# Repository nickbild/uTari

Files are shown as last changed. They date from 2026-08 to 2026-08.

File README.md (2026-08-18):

# µTari

µTari (pronounced micro-Tari) is an Atari 2600, only smaller. 

An original 2600 PCB measures about 9.75 x 5.25 inches. The µTari PCB is 4.7 x 3.5 inches, making it roughly one-third the size of the original. All of the original chips (6507 CPU, TIA, RIOT) were used in making the µTari — it's the real deal, not an emulator or FPGA.

<table>
  <tr>
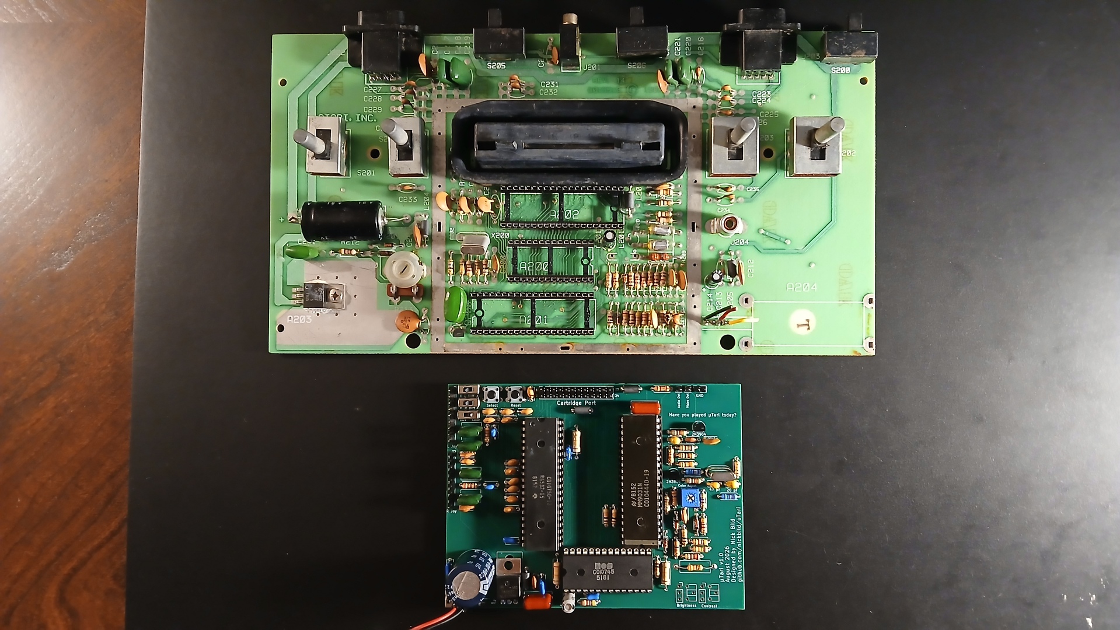
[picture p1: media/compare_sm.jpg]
Original Atari 2600 PCB compared with the smaller µTari PCB
    <td></td>
  </tr>
  <tr>
    <td align="center"><em>Original Atari 2600 PCB (top) compared with the µTari PCB (bottom).</em></td>
  </tr>
</table>

**Check out the video on YouTube:**
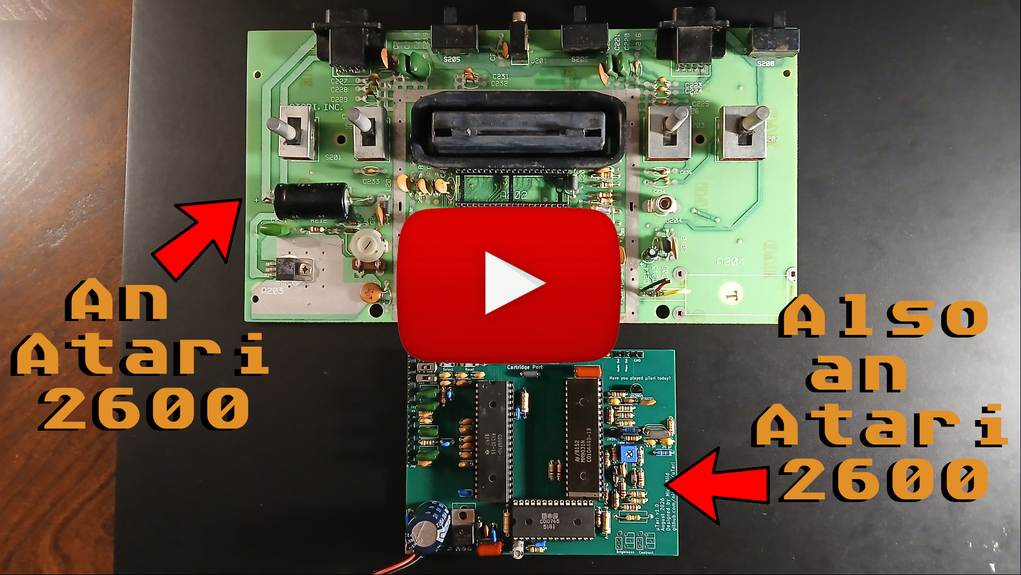
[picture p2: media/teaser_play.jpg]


## How

The Atari 2600 has large switches, as well as controller and cartridge ports, that are quite nice to have for a home console. I have replaced the large switches with tiny switches and buttons. The ports have been replaced with pin headers because my eventual plan is to turn this into a handheld, so I don't want ports on the main board.

Aside from that, I removed the RF modulator (which is normally at the bottom right of the 2600 PCB) and did a composite mod that replaces it with a single transistor and two resistors. That saves a fair amount of space and produces a cleaner signal that is compatible with more modern TVs. Empty spaces on the original PCB were also cut out. 

The remainder of the circuit is copied from the original Atari PCB. The 6507, TIA, and RIOT were transplanted to the new board. Since the rest of the components (mostly resistors, capacitors, transistors, and such) can still be purchased new, I used brand-new parts to leave the original board as intact as possible. All I would need to do is pop the chips back in the IC sockets for the 2600 to work again — no Ataris were harmed in the making of the µTari.

I started by breadboarding the circuit:

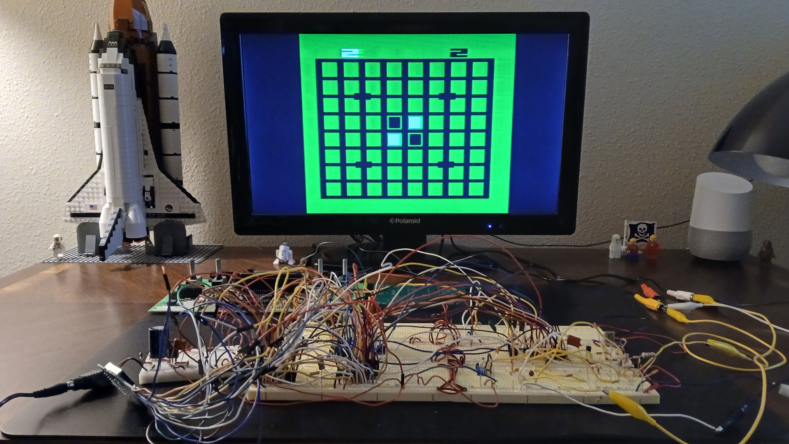
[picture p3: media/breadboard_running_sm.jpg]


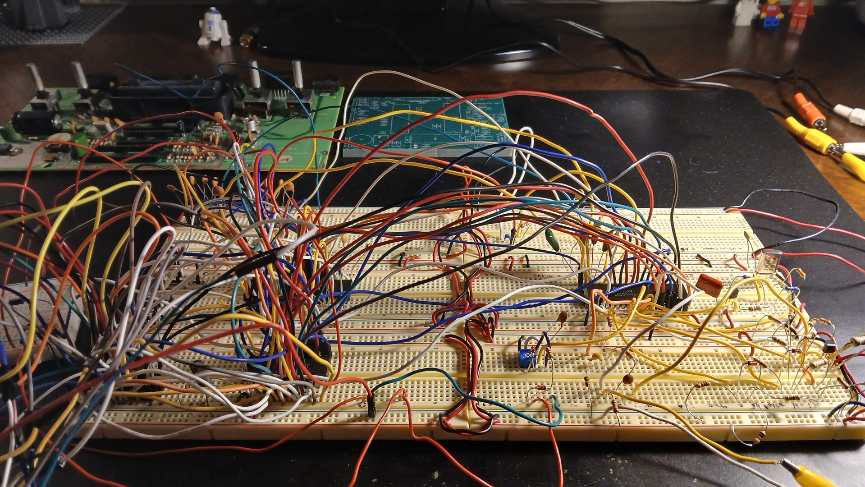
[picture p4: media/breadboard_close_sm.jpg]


Once I was convinced it was working properly, I drew the circuit diagram in KiCad before laying out a PCB and having it manufactured:

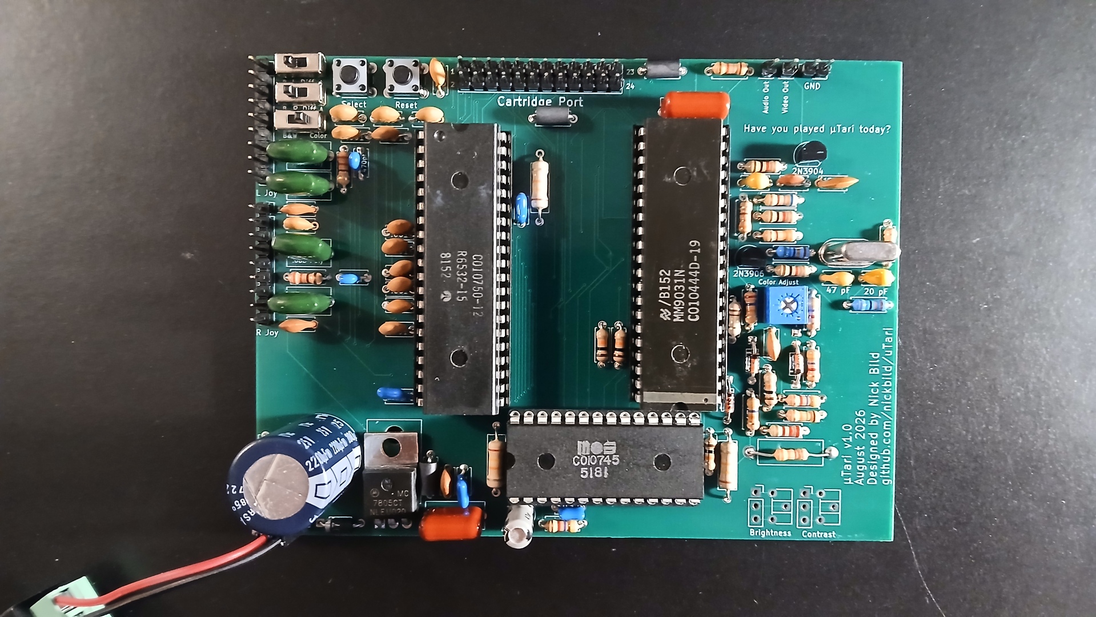
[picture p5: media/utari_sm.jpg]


It plays just like the real thing, because it is the real thing:

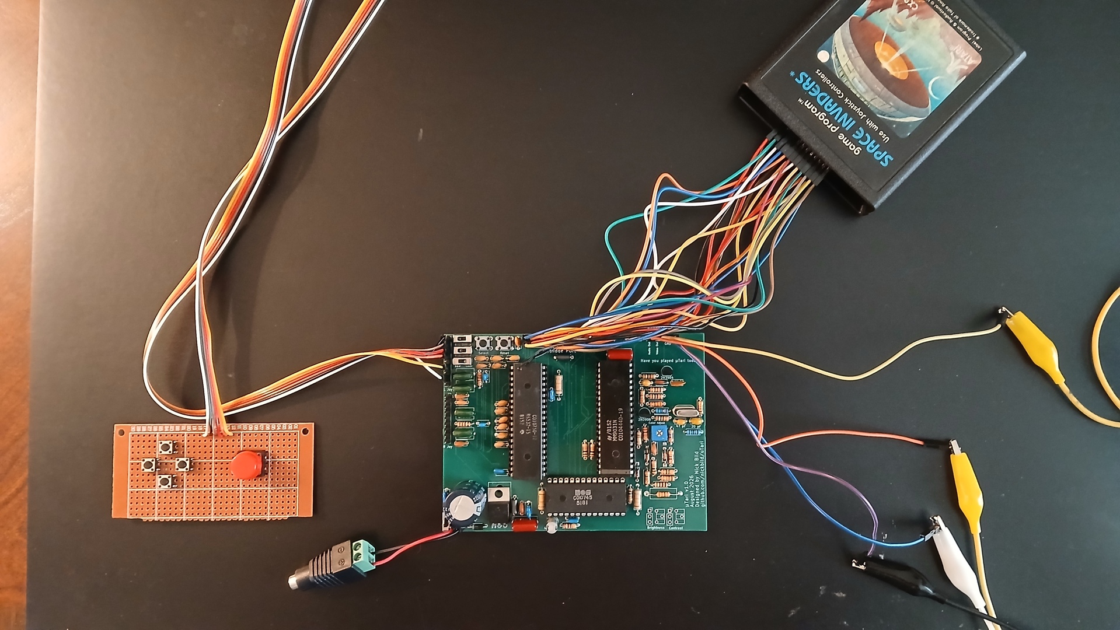
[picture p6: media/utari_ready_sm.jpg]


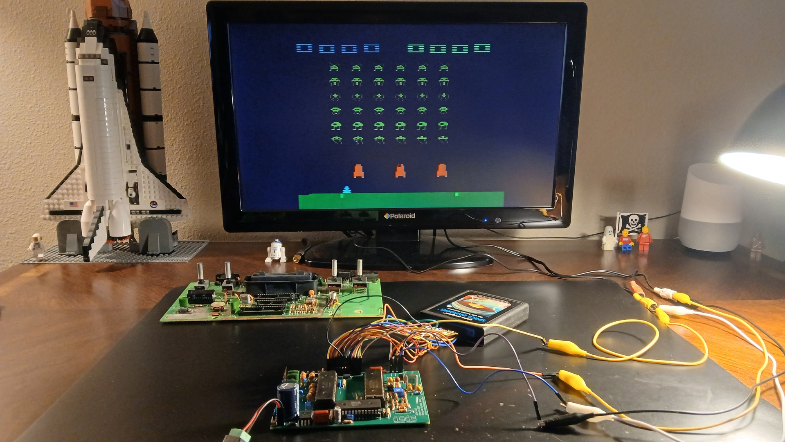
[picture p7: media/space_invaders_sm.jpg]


## About the Author

[Nick A. Bild, MS](https://nickbild79.firebaseapp.com/#!/)

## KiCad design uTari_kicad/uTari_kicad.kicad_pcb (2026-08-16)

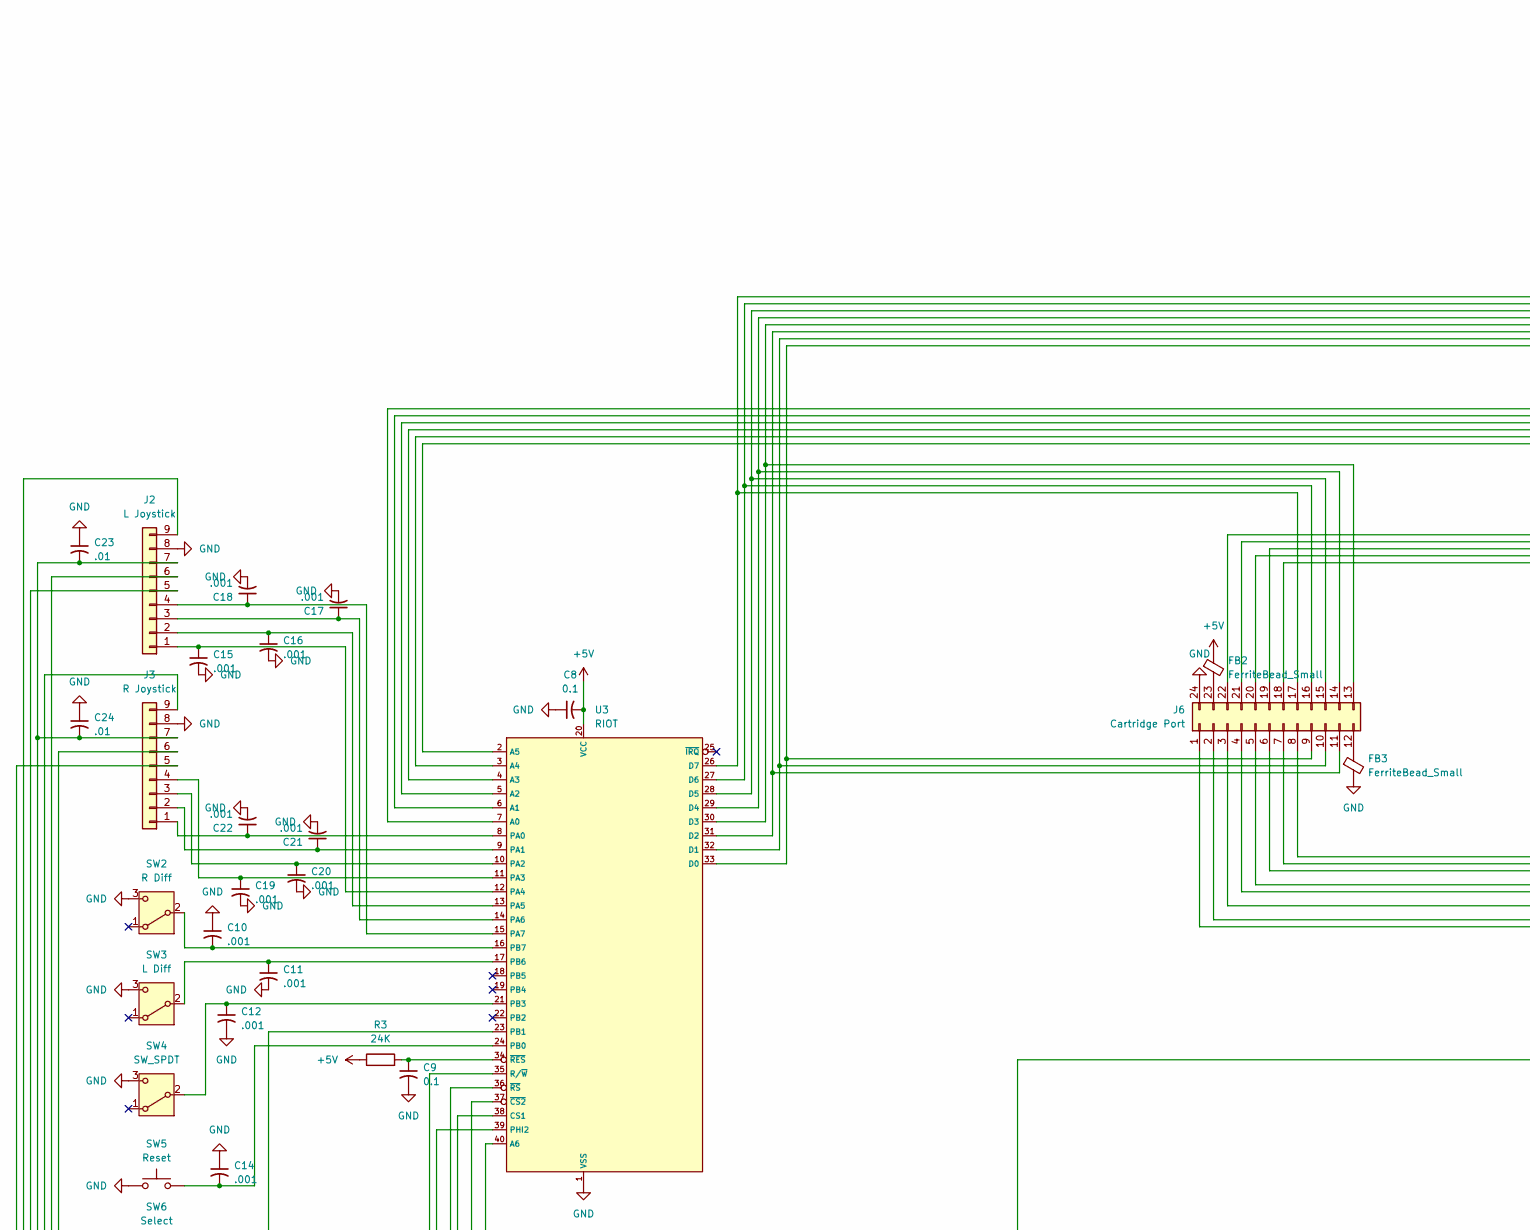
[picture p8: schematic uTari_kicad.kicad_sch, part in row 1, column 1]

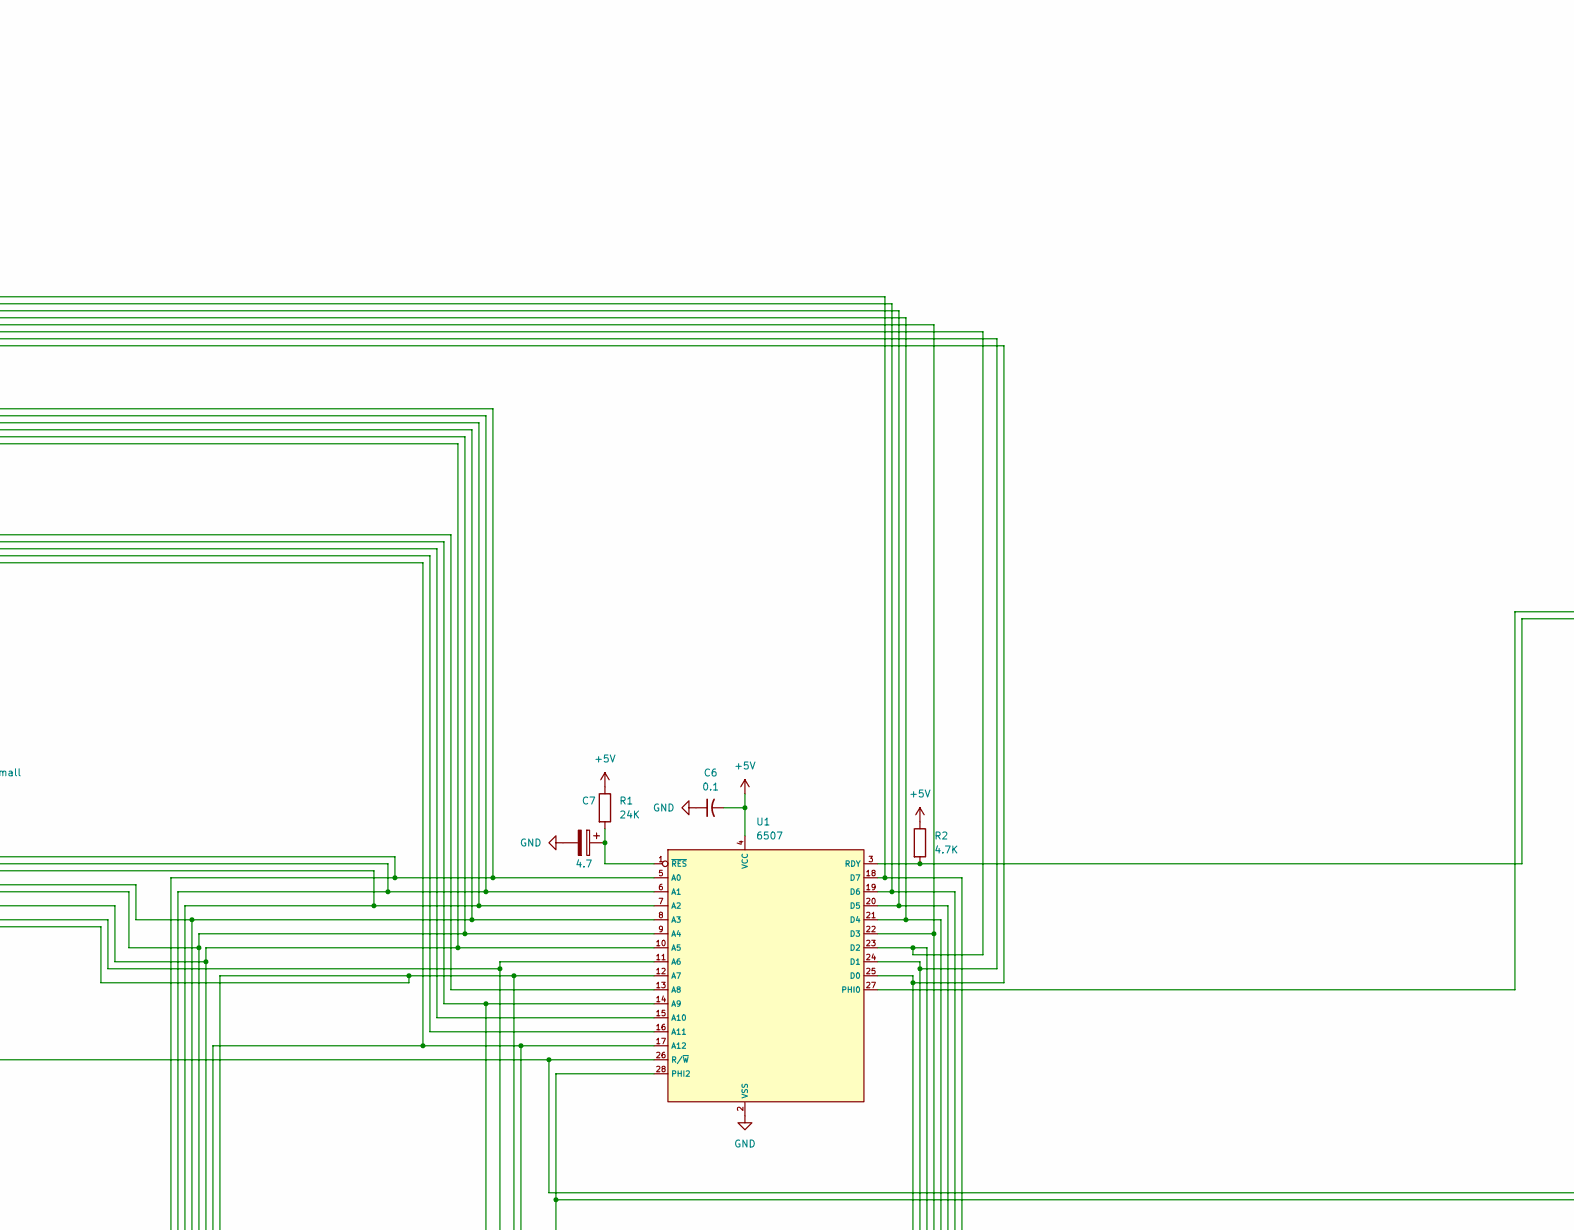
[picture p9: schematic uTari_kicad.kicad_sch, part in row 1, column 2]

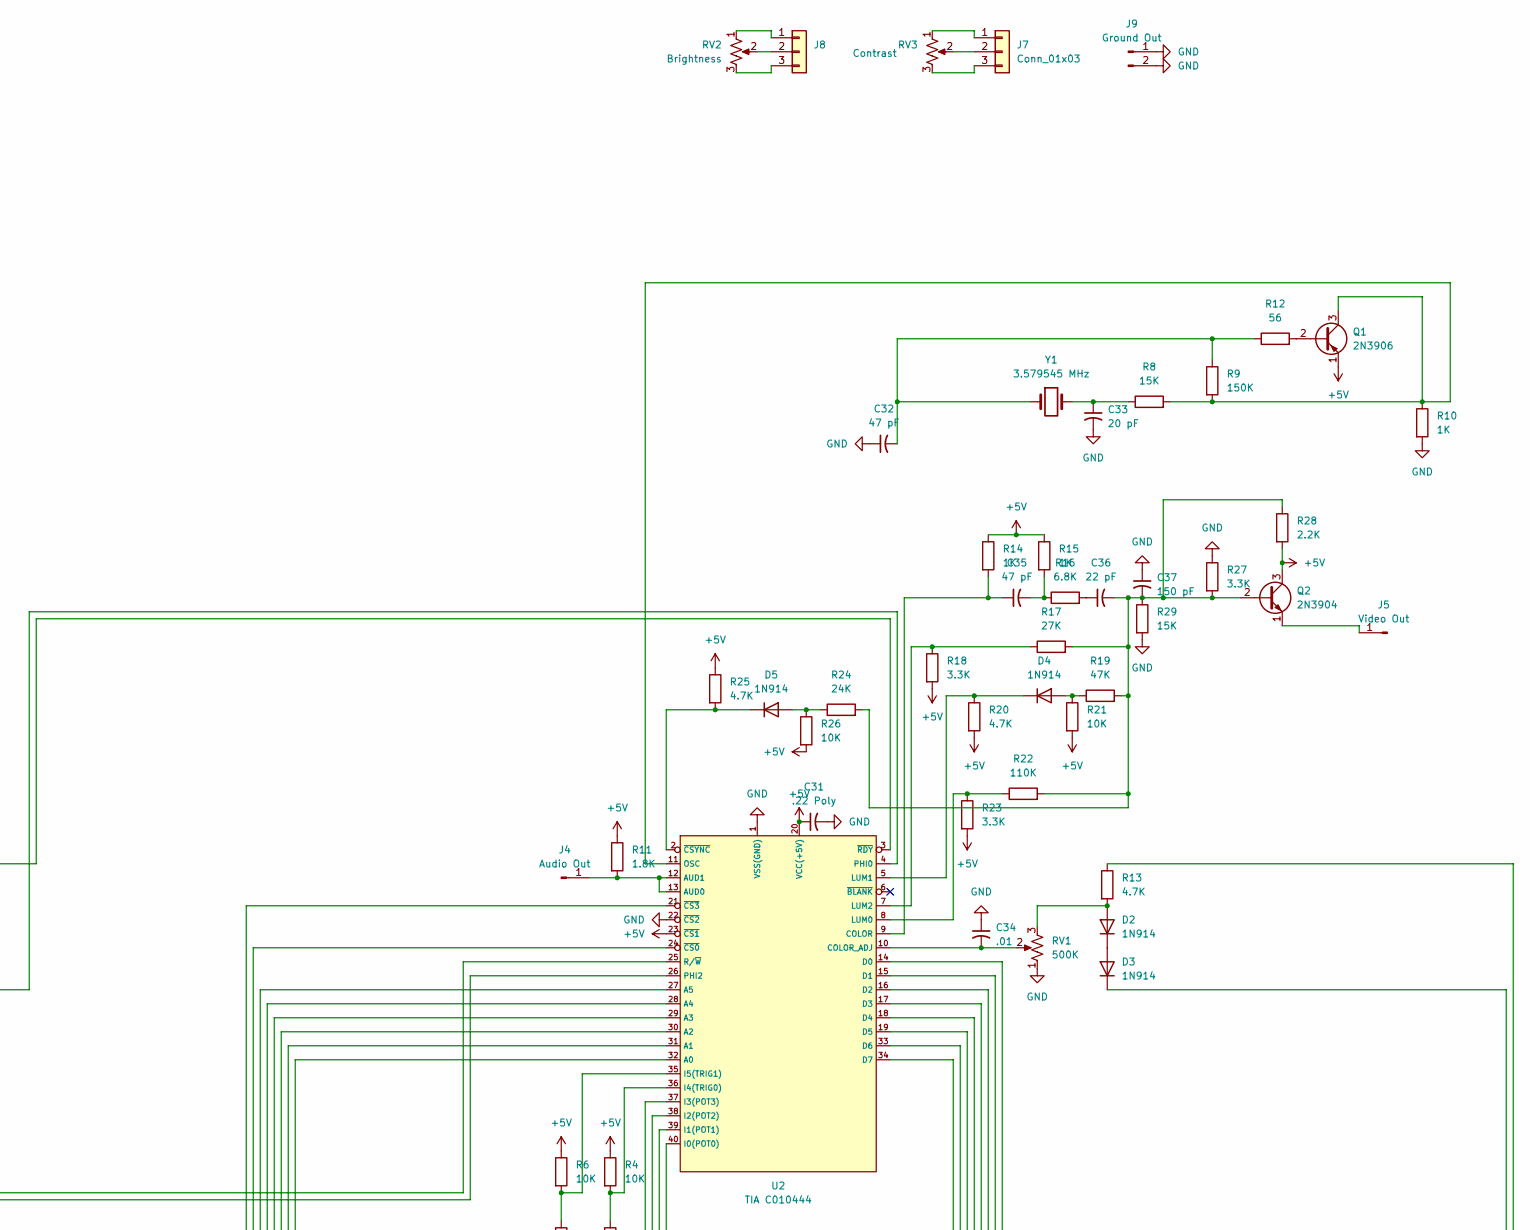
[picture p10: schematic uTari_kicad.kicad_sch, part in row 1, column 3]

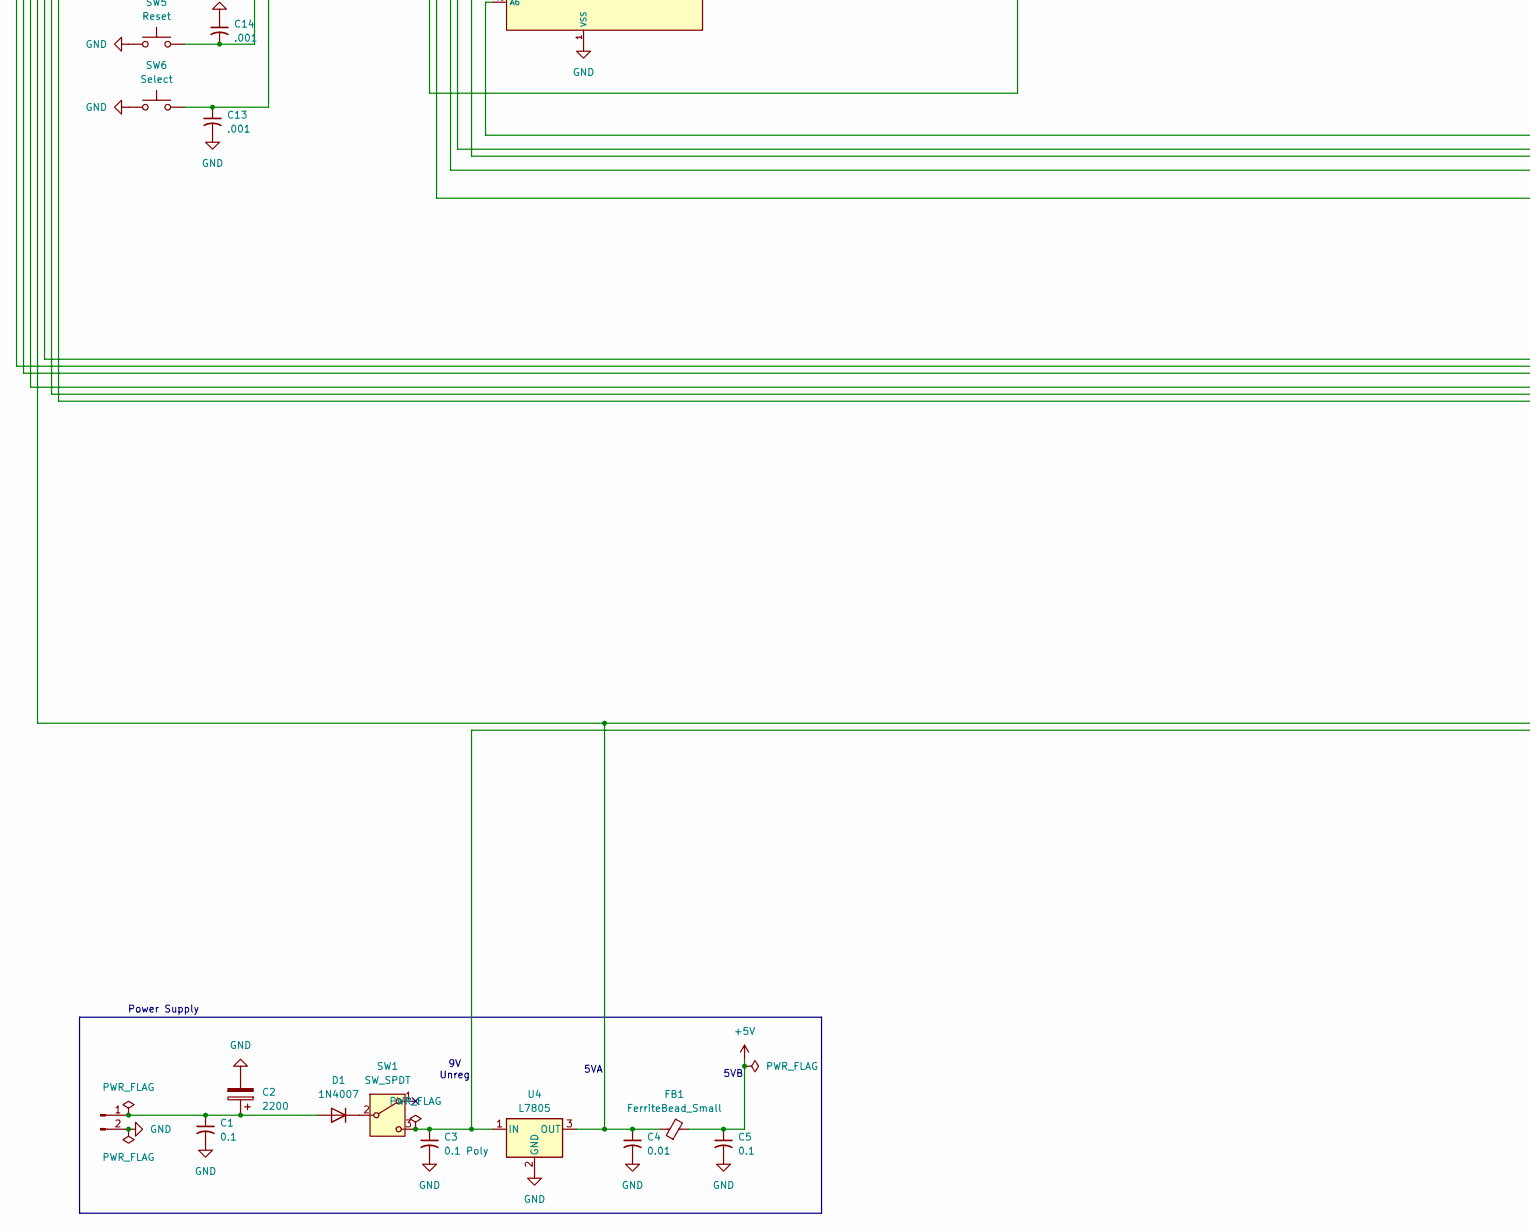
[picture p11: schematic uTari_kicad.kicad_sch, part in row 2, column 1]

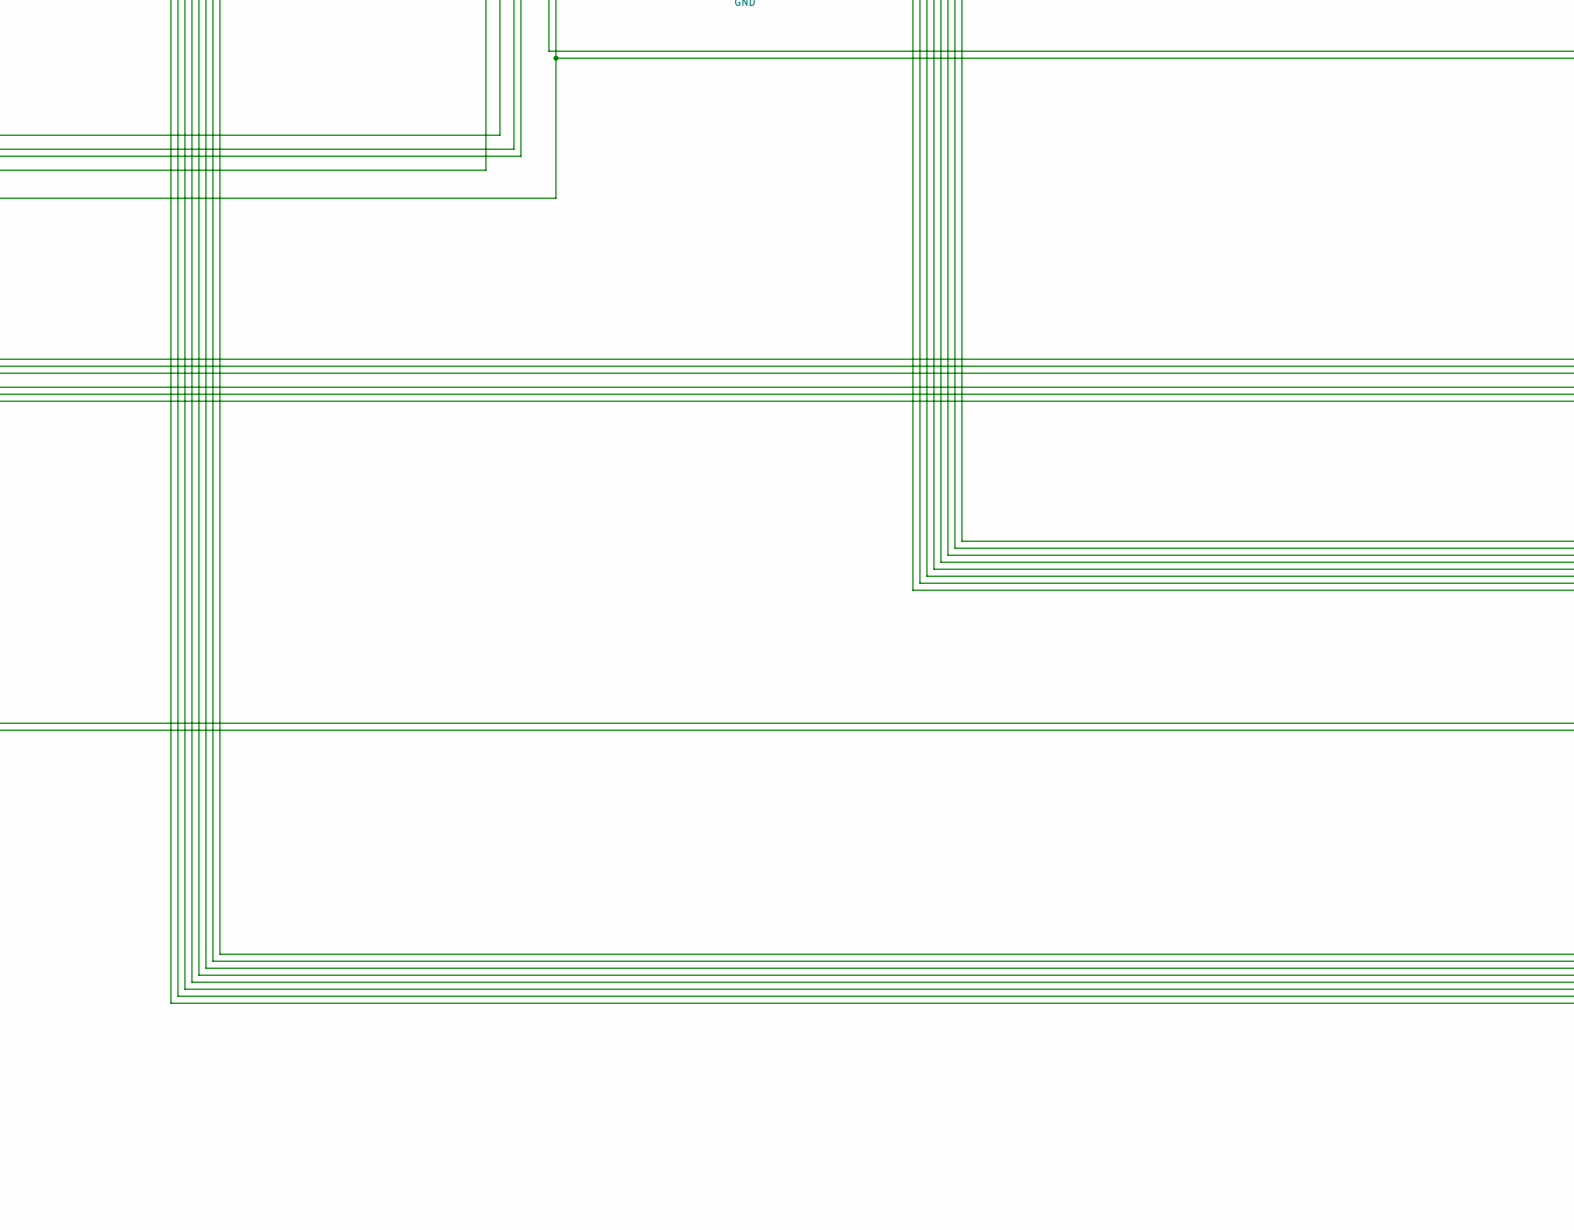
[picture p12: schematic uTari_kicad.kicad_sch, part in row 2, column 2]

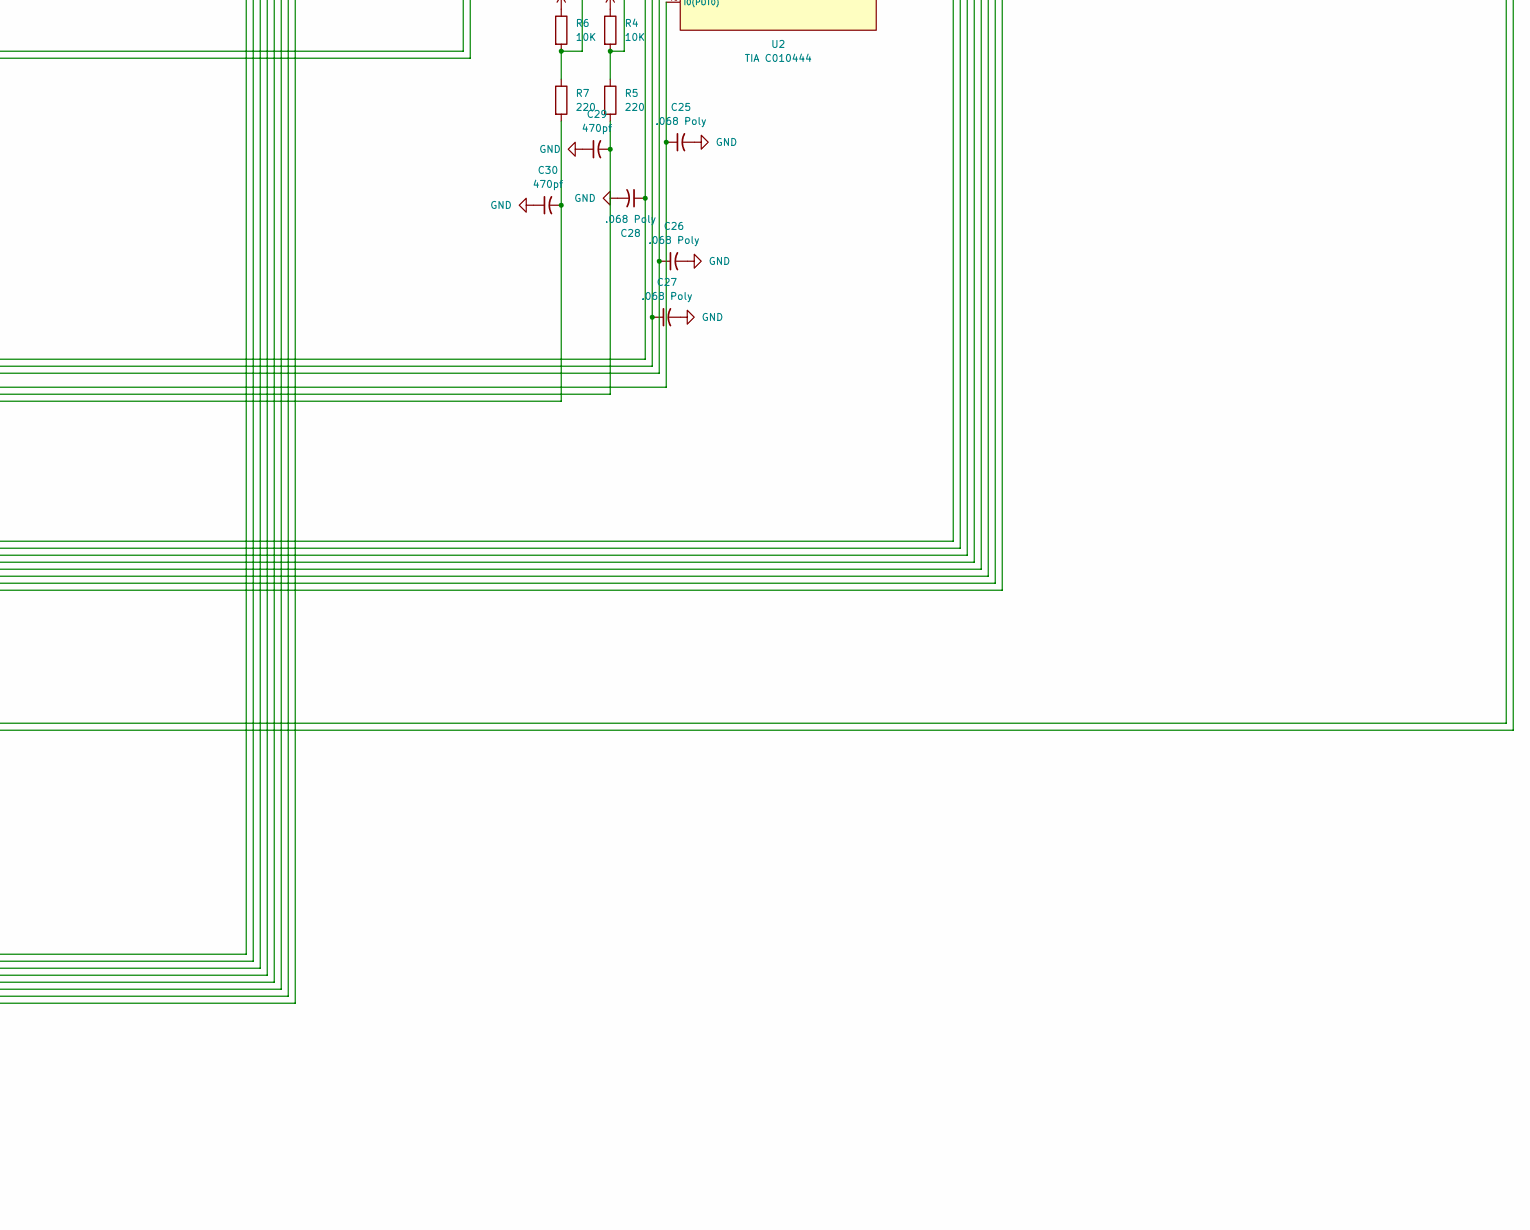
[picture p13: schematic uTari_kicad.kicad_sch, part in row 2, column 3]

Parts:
C1, C5, C6, C8, C9: 0.1; C_Disc_D5.0mm_W2.5mm_P5.00mm
C2: 2200; C_Radial_D16.0mm_H31.5mm_P7.50mm
C3: 0.1 Poly; C_Disc_D11.0mm_W5.0mm_P10.00mm
C4: 0.01; C_Disc_D5.0mm_W2.5mm_P5.00mm
C7: 4.7; CP_Radial_D5.0mm_P2.50mm
C10, C11, C12, C13, C14, C15, C16, C17, C18, C19, C20, C21, C22: .001; C_Disc_D5.0mm_W2.5mm_P5.00mm
C23, C24, C34: .01; C_Disc_D5.0mm_W2.5mm_P5.00mm
C25, C26, C27, C28: .068 Poly; C_Disc_D8.0mm_W5.0mm_P7.50mm
C29, C30: 470pf; C_Disc_D5.0mm_W2.5mm_P5.00mm
C31: .22 Poly; C_Disc_D11.0mm_W5.0mm_P10.00mm
C32, C35: 47 pF; C_Disc_D5.0mm_W2.5mm_P5.00mm
C33: 20 pF; C_Disc_D5.0mm_W2.5mm_P5.00mm
C36: 22 pF; C_Disc_D5.0mm_W2.5mm_P5.00mm
C37: 150 pF; C_Disc_D5.0mm_W2.5mm_P5.00mm
D1: 1N4007; D_DO-35_SOD27_P7.62mm_Horizontal
D2, D3, D4, D5: 1N914; D_DO-35_SOD27_P7.62mm_Horizontal
FB1, FB2, FB3: FerriteBead_Small; R_Axial_DIN0207_L6.3mm_D2.5mm_P7.62mm_Horizontal
J1: Conn_01x02_Pin; PinSocket_1x02_P2.54mm_Vertical
J2: L Joystick; PinSocket_1x09_P2.54mm_Vertical
J3: R Joystick; PinSocket_1x09_P2.54mm_Vertical
J4: Audio Out; PinSocket_1x01_P2.54mm_Vertical
J5: Video Out; PinSocket_1x01_P2.54mm_Vertical
J6: Cartridge Port; PinSocket_2x12_P2.54mm_Vertical
J7, J8: Conn_01x03; PinSocket_1x03_P2.54mm_Vertical
J9: Ground Out; PinSocket_1x02_P2.54mm_Vertical
Q1: 2N3906; TO-92_Inline
Q2: 2N3904; TO-92_Inline
R1, R3, R24: 24K; R_Axial_DIN0309_L9.0mm_D3.2mm_P12.70mm_Horizontal
R2, R13, R20, R25: 4.7K; R_Axial_DIN0207_L6.3mm_D2.5mm_P7.62mm_Horizontal
R4, R6, R21, R26: 10K; R_Axial_DIN0207_L6.3mm_D2.5mm_P7.62mm_Horizontal
R5, R7: 220; R_Axial_DIN0207_L6.3mm_D2.5mm_P7.62mm_Horizontal
R8, R29: 15K; R_Axial_DIN0207_L6.3mm_D2.5mm_P7.62mm_Horizontal
R9: 150K; R_Axial_DIN0207_L6.3mm_D2.5mm_P7.62mm_Horizontal
R10, R14, R15: 1K; R_Axial_DIN0207_L6.3mm_D2.5mm_P7.62mm_Horizontal
R11: 1.8K; R_Axial_DIN0207_L6.3mm_D2.5mm_P7.62mm_Horizontal
R12: 56; R_Axial_DIN0207_L6.3mm_D2.5mm_P7.62mm_Horizontal
R16: 6.8K; R_Axial_DIN0207_L6.3mm_D2.5mm_P7.62mm_Horizontal
R17: 27K; R_Axial_DIN0207_L6.3mm_D2.5mm_P7.62mm_Horizontal
R18, R23: 3.3K; R_Axial_DIN0207_L6.3mm_D2.5mm_P7.62mm_Horizontal
R19: 47K; R_Axial_DIN0207_L6.3mm_D2.5mm_P7.62mm_Horizontal
R22: 110K; R_Axial_DIN0207_L6.3mm_D2.5mm_P7.62mm_Horizontal
R27: 3.3K; R_Axial_DIN0414_L11.9mm_D4.5mm_P15.24mm_Horizontal
R28: 2.2K; R_Axial_DIN0207_L6.3mm_D2.5mm_P7.62mm_Horizontal
RV1: 500K; Potentiometer_ACP_CA6-H2,5_Horizontal
RV2: Brightness; Potentiometer_ACP_CA6-H2,5_Horizontal
RV3: Contrast; Potentiometer_ACP_CA6-H2,5_Horizontal
SW1, SW4: SW_SPDT; PinHeader_1x03_P2.54mm_Vertical
SW2: R Diff; PinHeader_1x03_P2.54mm_Vertical
SW3: L Diff; PinHeader_1x03_P2.54mm_Vertical
SW5: Reset; SW_PUSH_6mm
SW6: Select; SW_PUSH_6mm
U1: 6507; DIP-28_W15.24mm
U2: TIA C010444; DIP-40_W15.24mm
U3: RIOT; DIP-40_W15.24mm
U4: L7805; TO-220-3_Horizontal_TabDown
Y1: 3.579545 MHz; Resonator-2Pin_W10.0mm_H5.0mm

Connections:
+5V: C5.1, C6.2, C8.2, C31.1, FB1.2, FB2.1, Q1.1 (E), Q2.3 (C), R1.1, R2.1, R3.1, R4.1, R6.1, R11.1, R14.1, R15.1, R18.2, R20.2, R21.2, R23.2, R25.1, R26.2, R28.2, U1.4 (VCC), U2.20 (VCC(+5V)), U2.23 (~CS1), U3.20 (VCC); also elsewhere on the board
GND: C1.2, C2.2, C3.2, C4.2, C5.2, C6.1, C7.2, C8.1, C9.2, C10.1, C11.2, C12.2, C13.2, C14.1, C15.2, C16.2, C17.2, C18.2, C19.2, C20.2, C21.2, C22.2, C23.1, C24.1, C25.2, C26.2, C27.2, C28.2, C29.1, C30.1, C31.2, C32.1, C33.2, C34.1, C37.1, FB3.2, J1.2, J2.8, J3.8, J6.24, J9.1, J9.2, R10.2, R27.1, R29.2, RV1.1, SW2.3 (C), SW3.3 (C), SW4.3 (C), SW5.1, SW6.1, U1.2 (VSS), U2.1 (VSS(GND)), U2.22 (~CS2), U3.1 (VSS), U4.2 (GND); also elsewhere on the board
unnamed: C32.2, R9.1, R12.1, Y1.1
unnamed: C33.1, R8.1, Y1.2
unnamed: C35.2, R15.2, R16.1
unnamed: C36.1, R16.2
unnamed: C1.1, C2.1, D1.2 (A), J1.1
unnamed: D1.1 (K), SW1.2 (B)
unnamed: D2.2 (A), R13.2, RV1.3
unnamed: D2.1 (K), D3.2 (A)
unnamed: C4.1, C23.2, C24.2, D3.1 (K), FB1.1, J2.7, J3.7, U4.3 (OUT)
unnamed: D4.2 (A), R19.1, R21.1
unnamed: D4.1 (K), R20.1, U2.5 (LUM1)
unnamed: D5.2 (A), R24.1, R26.1
unnamed: D5.1 (K), R25.2, U2.2 (~CSYNC)
unnamed: C15.1, J2.1, U3.12 (PA4)
unnamed: C16.1, J2.2, U3.13 (PA5)
unnamed: C17.1, J2.3, U3.14 (PA6)
unnamed: C18.1, J2.4, U3.15 (PA7)
unnamed: C25.1, J2.5, U2.40 (I0(POT0))
unnamed: C29.2, J2.6, R5.2
unnamed: C26.1, J2.9, U2.39 (I1(POT1))
unnamed: C22.1, J3.1, U3.8 (PA0)
unnamed: C21.1, J3.2, U3.9 (PA1)
unnamed: C20.1, J3.3, U3.10 (PA2)
unnamed: C19.1, J3.4, U3.11 (PA3)
unnamed: C27.1, J3.5, U2.38 (I2(POT2))
unnamed: C30.2, J3.6, R7.2
unnamed: C28.1, J3.9, U2.37 (I3(POT3))
unnamed: J4.1 (Pin_1_1), R11.2, U2.12 (AUD1), U2.13 (AUD0)
unnamed: J5.1 (Pin_1_1), Q2.1 (E)
unnamed: J6.1, U1.12 (A7), U2.21 (~CS3), U3.38 (CS1)
unnamed: J6.2, U1.11 (A6), U3.40 (A6)
unnamed: J6.3, U1.10 (A5), U2.27 (A5), U3.2 (A5)
unnamed: J6.4, U1.9 (A4), U2.28 (A4), U3.3 (A4)
unnamed: J6.5, U1.8 (A3), U2.29 (A3), U3.4 (A3)
unnamed: J6.6, U1.7 (A2), U2.30 (A2), U3.5 (A2)
unnamed: J6.7, U1.6 (A1), U2.31 (A1), U3.6 (A1)
unnamed: J6.8, U1.5 (A0), U2.32 (A0), U3.7 (A0)
unnamed: J6.9, U1.25 (D0), U2.14 (D0), U3.33 (D0)
unnamed: J6.10, U1.24 (D1), U2.15 (D1), U3.32 (D1)
unnamed: J6.11, U1.23 (D2), U2.16 (D2), U3.31 (D2)
unnamed: FB3.1, J6.12
unnamed: J6.13, U1.22 (D3), U2.17 (D3), U3.30 (D3)
unnamed: J6.14, U1.21 (D4), U2.18 (D4), U3.29 (D4)
unnamed: J6.15, U1.20 (D5), U2.19 (D5), U3.28 (D5)
unnamed: J6.16, U1.19 (D6), U2.33 (D6), U3.27 (D6)
unnamed: J6.17, U1.18 (D7), U2.34 (D7), U3.26 (D7)
unnamed: J6.18, U1.17 (A12), U2.24 (~CS0), U3.37 (~CS2)
unnamed: J6.19, U1.15 (A10)
unnamed: J6.20, U1.16 (A11)
unnamed: J6.21, U1.14 (A9), U3.36 (~RS)
unnamed: J6.22, U1.13 (A8)
unnamed: FB2.2, J6.23
unnamed: J7.1, RV3.1
unnamed: J7.2, RV3.2
unnamed: J7.3, RV3.3
unnamed: J8.1, RV2.1
unnamed: J8.2, RV2.2
unnamed: J8.3, RV2.3
unnamed: Q1.2 (B), R12.2
unnamed: Q1.3 (C), R8.2, R9.2, R10.1, U2.11 (OSC)
unnamed: C36.2, C37.2, Q2.2 (B), R17.2, R19.2, R22.2, R24.2, R27.2, R28.1, R29.1
unnamed: C3.1, R13.1, SW1.3 (C), U4.1 (IN)
unnamed: C10.2, SW2.2 (B), U3.16 (PB7)
unnamed: C11.1, SW3.2 (B), U3.17 (PB6)
unnamed: C12.1, SW4.2 (B), U3.21 (PB3)
unnamed: U1.27 (PHI0), U2.4 (PHI0)
unnamed: U1.28 (PHI2), U2.26 (PHI2), U3.39 (PHI2)
unnamed: R2.2, U1.3 (RDY), U2.3 (~RDY)
unnamed: U1.26 (R/~W), U2.25 (R/~W), U3.35 (R/~W)
unnamed: C7.1, R1.2, U1.1 (~RES)
unnamed: C35.1, R14.2, U2.9 (COLOR)
unnamed: C34.2, RV1.2, U2.10 (COLOR_ADJ)
unnamed: R4.2, R5.1, U2.36 (I4(TRIG0))
unnamed: R6.2, R7.1, U2.35 (I5(TRIG1))
unnamed: R22.1, R23.1, U2.8 (LUM0)
unnamed: R17.1, R18.1, U2.7 (LUM2)
unnamed: C14.2, SW5.2, U3.24 (PB0)
unnamed: C13.1, SW6.2, U3.23 (PB1)
unnamed: C9.1, R3.2, U3.34 (~RES)

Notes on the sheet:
9V Unreg
5VA
5VB
Power Supply

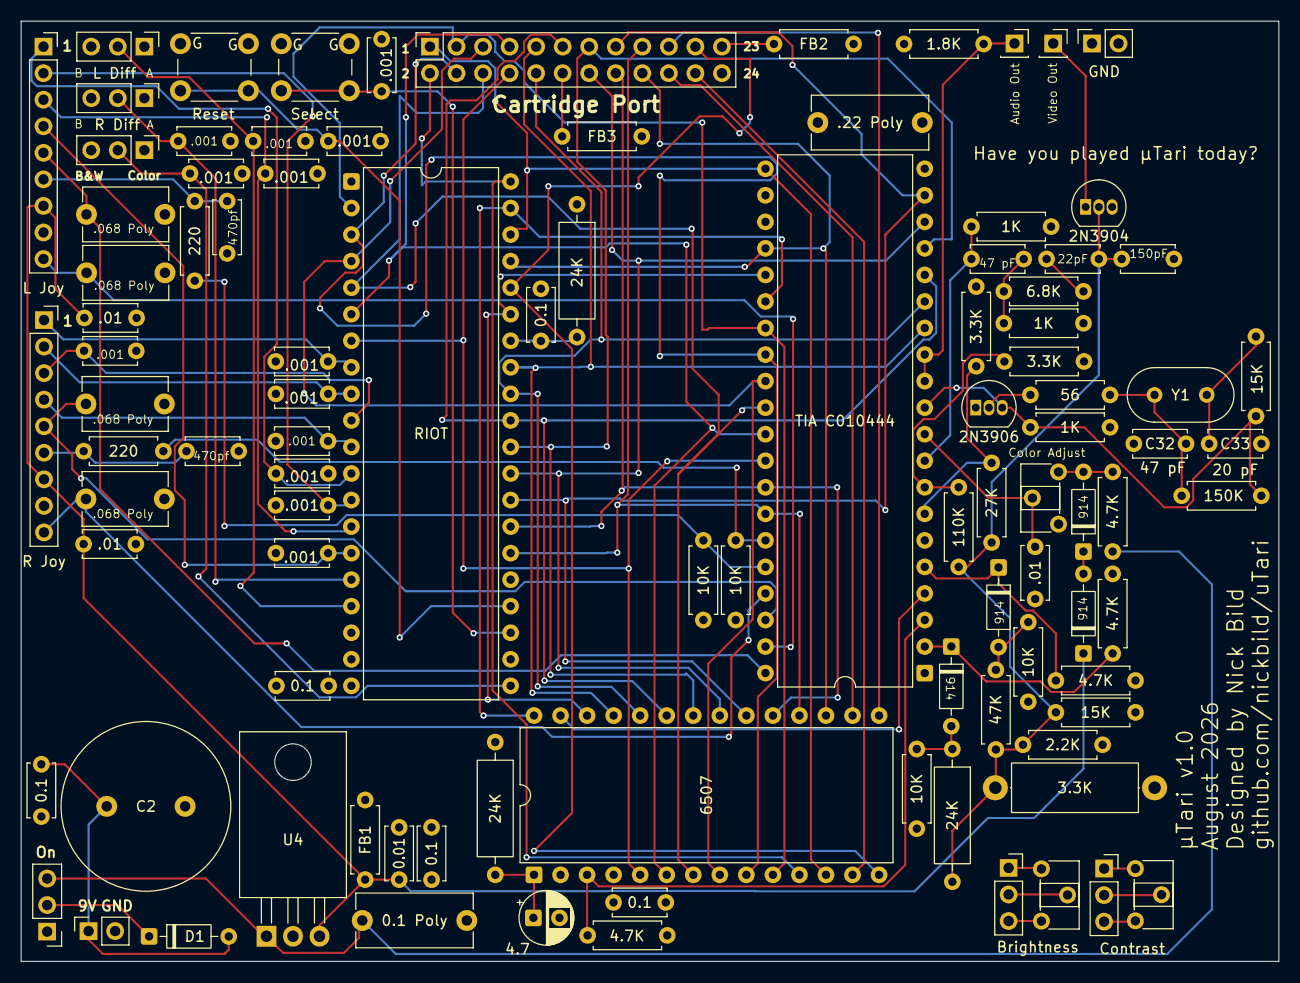
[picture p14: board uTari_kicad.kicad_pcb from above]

Board: 4 copper layers, 120.3 x 90.0 mm, 99 parts (0 on the bottom side), 81 nets.

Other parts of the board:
0.1: 0.1; C_Disc_D5.0mm_W2.5mm_P5.00mm

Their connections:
+5V: 0.1.2; also elsewhere on the board
GND: 0.1.1; also elsewhere on the board

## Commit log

2026-07-30 Initial commit.
    [uTari_kicad.kicad_pcb, uTari_kicad.kicad_sch]
2026-08-01 Save PCB progress.
    [uTari_kicad.kicad_pcb, uTari_kicad.kicad_sch]
2026-08-02 PCB complete.
    [uTari_kicad.kicad_pcb]
2026-08-16 Minor board updates.
    [uTari_kicad-B_Cu.gbl, uTari_kicad-B_Mask.gbs, uTari_kicad-B_Paste.gbp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]
